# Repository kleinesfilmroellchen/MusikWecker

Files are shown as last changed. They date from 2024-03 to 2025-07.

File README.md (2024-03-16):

# MusikWecker

MusikWecker ("music alarm clock") is an ESP8266-based alarm clock that plays music instead of horrible beeps.

Features:
- Music playback from SD card; various common formats like AAC, MP3, FLAC, WAV etc. supported
- Multiple, customizable alarms with various music playback modes
- Time synchronization via NTP
- Accurate local time and time zone support
- Many aesthetically appealing clock faces
- Low power consumption thanks to ESP8266 light sleep

## Development

Use a recent Arduino IDE or CLI, and make sure all libraries are up-to-date. (Library definition in a sketch config will follow shortly.)

Generate the auto-generated files by running `python .`. (Python >= 3.9, see requirements.txt) This is necessary when you change the generator scripts or when modifying or adding graphics. The compiler will only complain about missing headers the first time you forget this.

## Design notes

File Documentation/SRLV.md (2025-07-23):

# Single-bit Run Length Video (SRLV)

| | |
| --- | --- |
| Version | 0.3 |

Single-bit Run Length Video, abbreviated with SRLV, is a simple video format for black-and-white (1 bit per pixel) intended for software decoding on weak hardware. With the mildly optimized SRLV optimization in this repository, an ESP8266 (a single Xtensa core at 160MHz) can decode 833 frames per second (1.2ms per frame) from 80MHz flash. The small amount of time spent on decoding video allows a microcontroller core to perform all the other time-consuming duties of video playback (audio decoding, I2S communication with the audio DAC, SPI communication when reading audio and/or video from an SD card, I2C or SPI communication with the display) without much worry that the video decoding part will slow it down.

The `compression` directory contains the Python SRLV encoder. It's currently not very configurable apart from the input file, and there's some commented-out code that was used in developing the codec. If you are interested, you can play with these to come up with an even better scheme. Please leave a PR in this case and I may update SRLV (which may include a rename, since the name describes the compression scheme precisely).

> [!NOTE]
> Notes like this one are purely informational and do not specify the format beyond the specification text.

- auto-gen TOC;
  {:toc}

## Video Format

SRLV only performs intra-frame compression, and allows reusing identical frames (such as relatively common pure white or black frames). At present, only the single-frame format of SRLV is specified, and it is not containerized, so external knowledge of the video's dimensions are required to decode it correctly. A simple container format will be specified at a later point and added to this document.

## Frame format

This section specifies a single SRLV frame's raw format. Such frames may be stored using the `srlvf` (SRLV Frame) extension, and `image/srlvf` MIME type. Note that since this is a raw uncontainerized frame, there is no information about the frame's dimensions.

Encoding a frame is done with the following steps:

- The frame is converted to 1BPP XBM-compatible bit layout, including padding.
- The frame is optionally encoded as an inter-frame delta, i.e. a difference from the previous frame.
- Alternatively, the frame's scanlines are optionally converted to a back-and-forth (snake) format.
- The binary data is compressed using one of two methods:
  - Alternating run-length encoding followed by packing with nibble/byte entropy coding.
  - Pixel delta coding followed by black-run/raw coding.

There are six ways of encoding a frame. The numeric value of each method is prefixed as a byte in front of the encoded data, and the name given here will be used throughout the specification.

| Method | Name | Encoding ID |
| --- | --- | --- |
| RLE with nibble/byte entropy coding | Nibble | 0 |
| RLE with nibble/byte entropy coding and inter-frame delta | Nibble Delta  | 1 |
| RLE with nibble/byte entropy coding and snaking scanline reshuffling | Nibble Snake  | 2 |
| Pixel delta with black-run/raw coding | Pokémon | 3 |
| Pixel delta with black-run/raw coding and inter-frame delta | Pokémon Delta | 4 |
| Pixel delta with black-run/raw coding and snaking scanline reshuffling | Pokémon Snake | 5 |

Decoding simply performs the encoding steps in reverse order, using the encoding method specifier to decide which decoding steps (including the two optional preprocessing steps) to perform. Many embedded applications can already use images in XBM format, so the first step doesn't usually have to be applied in reverse in the decoder.

### Conversion to XBM

Frames contain one bit per pixel. The conventional interpretation is 1 = white, 0 = black, but depending on the context any two-color mapping is possible. It is recommended that 1 be assigned the brighter color.

Individual pixel's bits are packed into bytes according to XBM format. This means that pixels are first arranged into a left-to-right, top-to-bottom bitstream. Within the bitstream, consecutive scanlines are therefore arranged top-to-bottom, and the pixels in a scanline appear left-to-right.

> [!NOTE]
> This bit order is equivalent, among many others, to the Quite OK Image Format's (QOI) pixel order, the draw order for CRT televisions, as well as most video signals.

The bitstream is split into bytes, with zero padding at the end. Each byte contains the bits in LSB to MSB order, matching the X Bitmap (XBM) encoding format.

> [!NOTE]
> Run-length encoding does not care about the byte layout, just the bitstream with zero padding. The byte format is specified so that the output of the decompressor, which necessarily needs to have a byte-level format, is properly defined.

### Inter-frame delta coding

This preprocessing step encodes the bitstream as a delta from the previous frame. The unencoded bitstream $y_0$ of the previous frame is bit-wise XORed with the unencoded bitstream $y_1$ of the current frame, such that each bit of the output $x_1$ is given as $x_1[i] = y_0[i] + y_1[i]$.

> [!NOTE]
> For implementation, a byte-wise XOR on the XBM-formatted data of each frame has the same effect as the bitwise XOR.

Inter-frame delta coding methods cannot be used on the first frame.

### Scanline snake reshuffling

This preprocessing step reorders bits in the image before compression / after decompression. The final result is a bit order that "snakes" back and forth across the image. This processing step cannot be combined with inter-frame delta coding.

> [!NOTE]
> Combining snake and delta coding rarely yields better compression under either of the two schemes, so it was removed to speed up close-to-optimal encoding and simplify decoding.

When performing snake reshuffling, every second scanline (horizontal row of pixels) of the image is reversed. The first scanline is not reversed. Reversing means full bit reversal, not just byte reversal. This has the effect that the bits do not scan the image scanline-wise left-to-right, but alternatingly left-to-right and then right-to-left. 

It is recommended to use byte-aligned image widths (pixel count divisible by 8) to accelerate implementations. Some implementations can only handle encoding modes 2 and 5 when this is the case.

### "Nibble" compression

The frame bitstream is run-length encoded using alternating runs of black and white pixels. The first run is black, while the second is white, the third is black again and so on. A run may have any length of 0 to 127 (both inclusive). Runs of length 0 are explicitly valid.

> [!NOTE]
> Run length 0 is used to split long runs up without complicating the format with variable-length codes. For instance, a run of 300 black can be encoded as a 127-bit run of black, a 0-bit run of white (meaning no white pixels at all), another pair of those, and finally a 46-bit run of black:
>
> `0x7f 0x00 0x7f 0x00 0x2e`
>
> For arbitrary data, run length 0 is absolutely necessary.

The final run may be shorter than the remaining number of bits. In this case, the run extends to the end of the bitstream.

> [!NOTE]
> This rule allows saving on many split runs like above for large single-color surfaces, especially when they cover most or all of the image. For example, solid black may be encoded with empty data and solid white with `0x00` regardless of the image size. This is one of the reasons that the image size (and therefore bitstream size) needs to be known.

RLE yields a list of numbers, each from 0 to 127 inclusive. Byte/nibble entropy coding packs these numbers into bytes, using one of two byte formats:

- Byte encoding: A single number is encoded in a byte.
- Nibble encoding: Two numbers are encoded in a byte, using the two nibbles. The top nibble is occupied by the first number in the RLE stream, and the bottom nibble is occupied by the second number.

The topmost bit (MSB) of a byte identifies the kind of coding used. `1` means byte encoding, while `0` means nibble encoding.

For byte encoding, the whole range of values is supported. For nibble encoding, the top nibble may occupy values 0-7 inclusive (using three bits), and the bottom nibble may occupy values 0-15 inclusive (using four bits).

> [!NOTE]
> There are many ways of packing the same numbers into this entropy coding scheme. The reference implementation probably does not implement the best one, and in fact for a while it had a significant inefficiency, restricting the bottom nibble to the same 0-7 range.

### "Pokémon" compression

The frame bitstream is first pixel-delta encoded, and then black portions are run-length encoded.

> [!NOTE]
> The name "Pokémon" was chosen for the pixel delta-based format since it was loosely inspired by part of the compression method used for encoding Pokémon battle sprites in Pokémon Red and Blue (1996/1998). This compression method, addressing many of the same issues as this one (highly limited memory and relatively limited processing power), is surprisingly sophisticated and very interesting in its own right (and the cause of the infamous glitch Pokémon MissingNo's appearance), details can be found [here](https://www.youtube.com/watch?v=aF1Yw_wu2cM).
>
> Pokémon usually performs better on images with large amounts of noise, as its overhead for fast-changing pixels is significantly less than with the simple RLE scheme.

To perform pixel-delta encoding, each pixel is encoded as the XOR of itself with the previous pixel in bitstream order. The previous pixel of the first pixel is black.

For the run-length coding of these deltas, each byte may encode either:

- a run of up to 128 pixels of black (0) or
- 7 uncompressed pixels, in LSB-to-MSB-order

The topmost bit (MSB) of a byte identifies the kind of coding used. `1` means black RLE, while `0` means raw encoding. For the RLE, a bias of 1 is used, so a codeword of `0x80` represents not a run of length 0, but length 1.

> [!NOTE]
> Unlike in the simple RLE, since arbitrary codewords can follow one another, it is not necessary to have runs of length 0.

If the data does not specify all pixel values, the rest of the pixels are filled with 0.

### Turtle compression

Data for a frame consists of a frame header (9 byte) followed by any number of objects drawn onto the image.

The frame header starts with an info byte of the form `i0000000`:

- `i` is a flag determining whether to invert the frame colors at the end. By default, white (1) pixels are drawn on top of a black (0) background. If inverted, frames effectively have black pixels drawn on top of a white background.

Following this are 8 bytes for the Huffman coding table. Each byte contains a 3-bit entry bitsize (biased by 1, so 1-8) and an entry. The bitsize occupies the topmost 3 bits while the entry itself is situated at the least significant bits and cut off according to the given bitsize. (Any bitsize above 5 is illegal, as the entry only has 5 bits available.)

The entries for the table are always in this order:

- 135L
- 90L
- 45L
- F1
- FN
- FX
- 45R
- 90R
- 135R

See below for command names. In the following only these command names are used, which are substituted with their respective Huffman code in each frame.

#### Objects

An object starts with two header bytes of the form `0xxxxxxx 0yyyyyyy`:

- `x` is the X offset of the first pixel.
- `y` is the Y offset of the first pixel.

For solid objects, turtle graphics logic is used. The turtle has a current position on the image, as well as a grid direction that is aligned to 45 degrees (i.e. diagonal or horizontal or vertical). The initial facing direction is always down right (positive X and Y). Any command instructs the turtle to optionally change its facing direction, and then take at least one step in that new direction. The commands are:

- `90L`: Rotate 90 degrees left, then take one step.
- `90R`: Rotate 90 degrees right, then take one step.
- `45L`: Rotate 45 degrees left, then take one step.
- `45L`: Rotate 45 degrees right, then take one step.
- `135L`: Rotate 135 degrees left, then take one step.
- `135R`: Rotate 135 degrees right, then take one step.
- `F1`: Move forward one step without rotating.
- `FN`: Move forward at least 2 steps without rotating.
- `FX`: Move forward until starting position or image border is reached.

The `FN` command is the only one with a single parameter, namely the number of steps to move forward. The steps are encoded using Rice-Golomb coding with order `k = 2` and bias 1, such that the step count 2 is encoded as value 1.

The turtle commands automatically end once the starting location is reached again. The starting position is always filled in, but there’s no initial step taken in the starting direction. Any surface enclosed by the edge drawn by the turtle is filled in. The usual even-odd filling algorithm is used: Any pixel is filled in if any line from it to infinity crosses through an odd number of edges. The filling algorithm disregards any existing objects in the image.

The object is combined onto the full image by means of an XOR operation for each pixel, i.e. every pixel filled by the object is inverted in the final image.

#### Single-pixel trailer

Single-pixel trailer objects are a list of pixels to be set.

After the same common header as the normal objects use, each following coordinate is encoded using Rice-Golomb coding with order `k = 5` and zig-zag coding, such that 1 -> 1, -1 -> 2, 2 -> 3, -2 -> 4, 3 -> 5 etc.

All pixel coordinates, each a pair (x, y), are encoded as the difference from the previous one.

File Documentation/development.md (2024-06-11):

# Developer Guide

Use the Arduino IDE or CLI. There's VSCode integration too!

clangd or the Microsoft C/C++ language server should work well.

Formatting with clang-format is necessary for contributions. The config is in the standard .clang-format, MusikWecker uses minimally modified WebKit style.

## Debugging and logging

Since the serial port's pins are in use for other purposes, debugging via serial is not possible. (There is an option in Definitions.h to enable serial setup and prints, but it does not work if SD card and I2S code is not disabled.) Instead, debugging via TCP has been implemented. The MusikWecker provides a TCP server on port 1000, and connecting to that TCP server allows you to receive log messages.

The TCP logging does not easily handle early boot messages, or early boot failures. Debugging those is exceptionally hard to impossible on the MusikWecker and comes down to trial and error, i.e. commenting and un-commenting code until an offending statement is found and using guesswork to determine the underlying issue. Sometimes, serial debugging is possible here; you may need to disable the SD card initialization and/or audio management initialization.

## If the Bad Apple demo is slow

(i.e. stuttery video playback, but fine audio playback)

Force all important I2S routines into IRAM, like so:

```cpp
// I2S.h in ESP8266 core libraries
// insert the IRAM_ATTR in the appropriate places:

  // from Stream
  virtual int IRAM_ATTR available();
  virtual int IRAM_ATTR read(); // Blocking, will wait for incoming data
  virtual int IRAM_ATTR peek(); // Blocking, will wait for incoming data   
  virtual void IRAM_ATTR flush();

  // from Print (see notes on write() methods below)
  virtual size_t IRAM_ATTR write(uint8_t);
  virtual size_t IRAM_ATTR write(const uint8_t *buffer, size_t size);
  virtual int IRAM_ATTR availableForWrite();

```

[An issue to enable this via a configurable option has been opened upstream](https://github.com/esp8266/Arduino/issues/9115).

## TODOs because I forget

Some of the things I still need to implement. In rough order of priority

### Must

- Bugs/QOL
	- File list doesn't reload everywhere when files are moved and deleted
	- Diagnostics page is broken
- The entire alarm system
	- Creating and deleting alarms
	- Alarm settings (which are available?)
	- Executing alarms
	- Correct wakeup before an alarm runs (at least 10s to allow WiFi reconnect)
- Software volume control
- Power saving shenanigans
	- Flash clock-down for the same reasons.
- Play music when selected in file view
- Important settings
	- Configure NTP update interval
		- 60s
		- 5min
		- 30min
		- 24h
	- Configure NTP server

### Want

- Nicer interface for yes/no selection menus
- Web UI for configuring more complex stuff
	- Name alarms
	- Specifying 
	- Rename files
- Talk to Home Assistant for updating alarm times (since HA has an easier time receiving alarm data from Google services and the like)
- MP3 player
	- "Currently playing" page (in the clock menu?)
	- Play entire folder
	- Index all music, allow playback by artist, album, etc.

### Nice to have

- Put together a BOM for making a single PCB for this
- Design a single PCB for this
- Manufacture a single PCB for this
- World domination

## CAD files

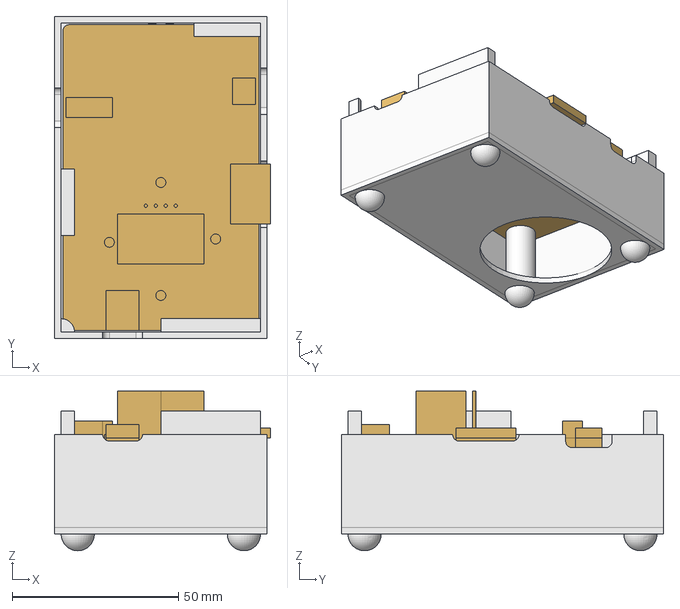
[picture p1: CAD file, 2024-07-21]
EDA/MusikWeckerCase.FCStd
65.0 x 97.0 x 48.0 mm
PCBModel
TopWithConnectors

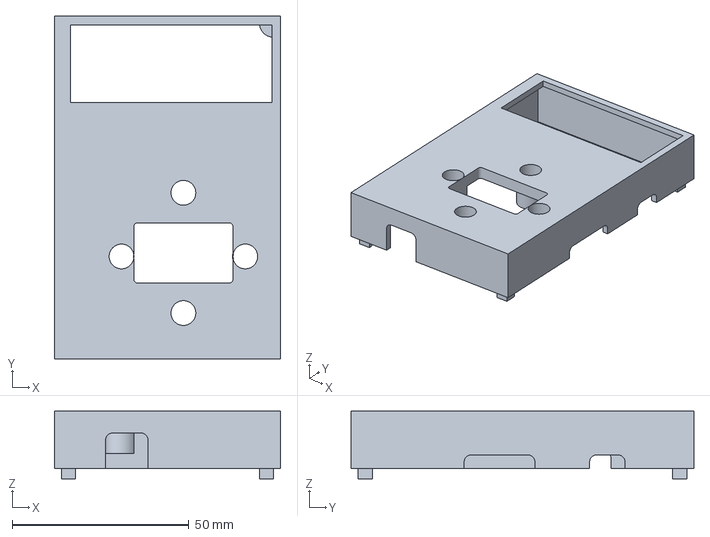
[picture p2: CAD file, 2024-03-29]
EDA/MusikWeckerCase_top.3mf
64.0 x 97.0 x 19.2 mm

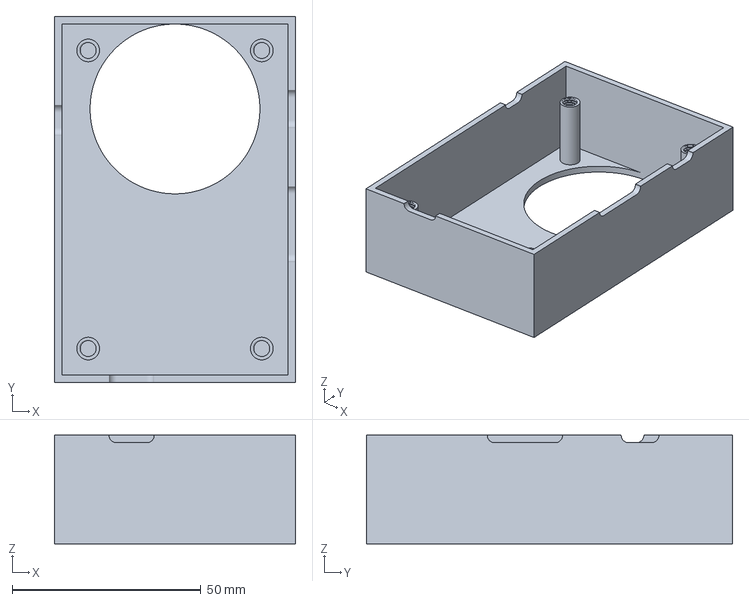
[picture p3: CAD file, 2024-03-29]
EDA/MusikWeckerCase_bottom.3mf
64.0 x 97.0 x 28.8 mm

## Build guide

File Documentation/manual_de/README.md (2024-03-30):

# Benutzerhandbuch für den MusikWecker

Dieses Benutzerhandbuch ist für Benutzer\*innen des MusikWeckers gedacht, nicht für Entwickler.

Diese Seite behandelt die Grundlagen des Weckers. Auf weiteren Seiten (Liste links) finden sich detaillierte Informationen zu anderen Aspekten.

- auto-gen TOC;
  {:toc}

## Bediengrundlagen

Der MusikWecker besitzt vier Knöpfe zur Bedienung, die jeweils eine übliche Funktion besitzen:

- _Rechts_: OK/Enter
- _Oben_: Zum darüberliegenden Menüpunkt navigieren
- _Unten_: Zum darunterliegenden Menüpunkt navigieren
- _Links_: Abbrechen, Menü verlassen

Wird ein Knopf längere Zeit gedrückt, so wird der Knopf wiederholt aktiviert.

In den meisten Menüs können Optionen dementsprechend durch Scrollen nach oben und unten ausgewählt werden. Eine Option wird durch _Rechts_ bestätigt, und _Links_ dient zum Abbrechen oder Verlassen des Menüs.

Wenn der Wecker in den Ruhezustand geht, kann nur _Links_ ihn aufwecken.

## Hauptmenü

Vom Startbildschirm aus (dem Uhrbildschirm) kann das Hauptmenü mittels _Rechts_ aufgerufen werden. Das Hauptmenü besteht aus den folgenden Elementen:

- Uhrdesign: Auswahl der Uhr, die angezeigt wird.
- Wecker: Konfiguration von Weckern.
- Dateiverwaltung: Verwaltung der Dateien auf der SD-Karte.
- Einstellungen: Verschiedene Einstellungen des MusikWeckers
- Diagnostik: Diagnosemenüs, die den detaillierten Zustand des Weckers zeigen.

## Einstellungen

Die folgenden Einstellungen sind verfügbar. Sie werden dauerhaft gespeichert und werden nach einem Neustart des Weckers wiederhergestellt.

- Auto-Abschaltung: Zeitdauer, nach der der Wecker in den Ruhezustand geht.
- Zeitzone: Zeitzone der Uhr. Die Zeitzonen sind von Osten nach Westen geordnet.
- Debugging: Firmware-Debugging. Dies aktiviert die Anzeige von Debugging-Nachrichten (in der Regel nur sichtbar, falls der Wecker kurz danach abstürzt), sowie verschiedene Debugging-Funktionen wie die Anzeige von Uhren-Zeichnungszeiten auf dem Startbildschirm.

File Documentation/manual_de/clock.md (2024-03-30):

# Uhr

Der Uhrbildschirm ist der Startbildschirm des Weckers. Er zeigt die aktuelle Uhrzeit entsprechend dem aktuellen Uhrdesign, das aktuelle Datum (falls aktiviert), sowie rechts oben mehrere Icons, die den Zustand des Weckers beschreiben:

- Funksymbol: Wecker ist mit einem WLAN-Netzwerk verbunden.
- Kreuz anstelle des Funksymbols: Wecker ist nicht mit einem Netzwerk verbunden.
- Uhr mit Funkwellen: Wecker hat soeben seine Uhrzeit synchronisiert. Dies geschieht für gewöhnlich jede Minute, und das Symbol wird einige Sekunden angezeigt.
- Wecker: Mindestens ein Wecker ist aktiv.
- Lautsprecher: Ton wird wiedergegeben.

## Uhrdesign

Das Uhrdesign-Menü (erreichbar im Hauptmenü) erlaubt die Auswahl des Uhrdesigns des Weckers. Wird die Auswahl in diesem Menü mehr als fünf Sekunden nicht bewegt, zeigt die rechte Seite des Bildschirms eine Vorschau des aktuell angewählten Designs. Durch _Rechts_ kann dieses Design ausgewählt werden.

Die folgenden Designs sind aktuell verfügbar:

- Digital: Einfache, große Digitaluhr ohne Sekundenanzeige.
- Digital (Sekunden): Identisch zur normalen Digitaluhr, allerdings mit Sekundenanzeige.
- Analog (minimalistisch): Analoguhr mit Stundenstrichen ohne Beschriftungen.
- Rotierende Segmente: Drei rotierende Segmente, die (von innen nach außen) Stunden, Minuten und Sekunden anzeigen. Die Größe des Segments entspricht dem Abstand eines analogen Zeigers von der Zwölf-Uhr-Position.
- Binär: Binäruhr, die von unten nach oben Stunden, Minuten und Sekunden als Binärzahl anzeigt.
- Binär (Tagsekunden): Binäruhr, die die Sekunden des Tages anzeigt.

## Uhrzeit und Zeitsynchronisation

Der Wecker ruft die aktuelle Uhrzeit über das Internet mithilfe des Network Time Protocols (NTP) ab. Da der Wecker die Uhrzeit nicht persistent speichert, ist er auf die Netzwerkzeitsynchronisation angewiesen, und zeigt beispielsweise nach dem Hochfahren bis zur ersten Netzwerkverbindung keine sinnvolle Uhrzeit an.

Zur Synchronisation muss auf einen NTP-Server zugegriffen werden, der im Idealfall jederzeit verfügbar sein sollte, damit eine Resynchronisierung zu beliebigen Zeitpunkten möglich ist. Aktuell wird immer der `europe.pool.ntp.org`-Server ausgewählt, der einen zufälligen europäischen NTP-Poolserver abruft. Der NTP-Pool ist allgemein zu empfehlen, da er auf viele tausende Server zurückgreifen kann und damit kaum störungsanfällig ist. In einer zukünftigen Firmwareversion werden diese NTP-Server als Auswahl zur Verfügung stehen:

- `pool.ntp.org`, `0.pool.ntp.org`, `1.pool.ntp.org`, `2.pool.ntp.org`, `3.pool.ntp.org`: Die globalen NTP-Poolserver. Die Server mit vorangestellter Ziffer sollten nur verwendet werden, falls die anderen nicht erreichbar sind.
- `africa.pool.ntp.org`, `asia.pool.ntp.org`, `europe.pool.ntp.org`, `north-america.pool.ntp.org`, `oceania.pool.ntp.org`, `south-america.pool.ntp.org`: Kontinentspezifische NTP-Pools, die entgegen dem globalen Pool bevorzugt werden sollten, da sie geographisch nähere Server und geringere Antwortzeiten verursachen.
- `de.pool.ntp.org`, `at.pool.ntp.org`, `ch.pool.ntp.org`: Länderspezifische NTP-Pools für DACH, die noch mehr einen Antwortzeit-Vorteil als die Kontinentalpools bieten.
- `time.nist.gov`: Zeitserverpool des staatlichen USA-Metrologieinstituts NIST. Empfehlenswert nur für Verwendung innerhalb der USA.
- `ptbtime1.ptb.de`, `ptbtime2.ptb.de`, `ptbtime3.ptb.de`, `ptbtime4.ptb.de`: Zeitserver der Physikalisch-Technischen Bundesanstalt. Empfehlenswert nur für Verwendung innerhalb Deutschlands.
- Gateway: Verwendet den aktuellen Netzwerk-Gateway als NTP-Server. In vielen einfachen Heimnetzwerken fungiert der Router bzw. Gateway auch als NTP-Server (dies kann beispielsweise bei den FRITZ!Box-Routern von AVM problemlos über das Webinterface eingerichtet werden). Bei seltenem Netzwerkwechsel ist der Vorteil hiervon eine sehr geringe Antwortzeit und Netzwerklast, sowie eine einfache und flexiblere Umkonfiguration der NTP-Server, die jetzt nur noch im Router vorgenommen werden müssen.

Unabhängig von der Zeitsynchronisation kann in den Einstellungen eine Zeitzone gewählt werden. Die Zeitzonendatenbank, welche beispielsweise Informationen über Sommerzeitumstellungen enthält, wird vom Wecker nicht automatisch aktualisiert und muss durch ein Firmware-Update erneuert werden. Dank der recht seltenen Änderungen in Zeitzonenkonfigurationen ist dies nur notwendig, wenn der Wecker erkennbar von der eigentlichen Uhrzeit in einer Zeitzone abweicht.

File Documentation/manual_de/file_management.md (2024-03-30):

# Dateiverwaltung

Der Wecker benutzt eine Micro-SD-Karte, um dort gespeicherte Musik zum Wecken zu verwenden. Er stellt außerdem grundlegende Dateiverwaltung zur Verfügung, allerdings muss die zu verwendende Musik vorher mit einem anderen Gerät auf der SD-Karte abgelegt werden.

- auto-gen TOC;
  {:toc}

## Kartenformat

Der Wecker unterstützt nur Karten, die ein FAT-Dateisystem (FAT16, FAT32, exFAT) haben und entsprechend dem SD-Standard formatiert sind. Die Formatierung nach diesen Kriterien wird z.B. vom offiziellen SD-Karten-Formatierungstool der SD Association durchgeführt, welches [hier](https://www.sdcard.org/downloads/formatter/) kostenlos heruntergeladen werden kann.

Zum Einlegen oder Entnehmen einer SD-Karte sollte der Wecker nicht eingeschaltet sein, da dies die Daten auf der SD-Karte beschädigen kann. Außerdem kann der Wecker mit dem Entnehmen oder Einlegen der SD-Karte zur Laufzeit nicht gut umgehen und stürzt eventuell ab.

## Dateiansicht

Verschiedene Menüs des Weckers bieten eine Dateiansicht, die die Dateien eines Verzeichnisses auflistet. Das sind z.B. das Lösch- und Verschiebemenü sowie die Menüs zur Auswahl einer Musikdatei für einen Wecker. Die Menüs besitzen immer denselben Aufbau: In einer Liste, wie auch in anderen Listenmenüs, werden die Dateien des aktuellen Ordners angezeigt, zwischen denen mit _Oben_ und _Unten_ navigiert werden kann. Die ersten beiden Einträge dieser Liste sind besonders.

Der erste Eintrag hat als Namen den vollständigen Pfad des aktuellen Verzeichnisses. Je nach Art des Menüs kann dieser Eintrag so wie andere Dateien ebenfalls angewählt werden, um das Verzeichnis (anstatt einer einzelnen Datei) anzuwählen. Beispielsweise kann ein Verzeichnis im Löschmenü angewählt werden, um das gesamte Verzeichnis zu löschen. Besteht keine Anwahlmöglichkeit für ein Verzeichnis (d.h. es können nur Dateien oder überhaupt nichts angewählt werden), so kann _Rechts_ dennoch betätigt werden, um die Verzeichnisansicht zu aktualisieren. (In der Regel sorgt dies nicht für eine sichtbare Änderung der Anzeige.)

Der zweite Eintrag hat als Namen "..". Dieser Eintrag beschreibt, so wie auch in Klammern angegeben ist, das Elternverzeichnis des aktuellen Verzeichnisses, also das nächste übergeordnete Verzeichnis. Die Anwahl dieses Eintrags öffnet das übergeordnete Verzeichnis in der Dateiansicht. (Dieser Eintrag hat keine Auswirkungen, sollte bereits das Basisverzeichnis der SD-Karte geöffnet sein.) Dazu ist wichtig zu bemerken, dass _Links_ absichtlich **nicht** das Elternverzeichnis öffnet, sondern das Dateimenü schließt und zum vorherigen Menü zurückkehrt. Dies erleichtert das Verlassen der Dateiansicht, wenn gerade ein tief verschachteltes Dateimenü geöffnet ist. Da der ".."-Eintrag der zweite Eintrag der Liste ist, ist es recht einfach, schnell einige Verzeichnisse nach oben zu navigieren.

Das Anwählen von Unterverzeichnissen, die als normale Einträge geführt werden, öffnet dieses Unterverzeichnis in der Dateiansicht. Soll dieses Verzeichnis selbst angewählt werden, kann in der jetzt sichtbaren Liste entsprechend der erste Eintrag gewählt werden.

Die Sortierung der gewöhnlichen Einträge hat aktuell technische Hintergründe und entspricht vermutlich dem Erstellzeitpunkt der Dateien bzw. Verzeichnisse.

## Dateiverwaltungsmenü

Das Menü "Dateiverwaltung", welches sich im Hauptmenü findet, ermöglicht generelle Verwaltung der Dateien auf der SD-Karte. Die folgenden Aktionen sind möglich:
- Dateiansicht: Ansicht der Dateien auf der SD-Karte. Aktuell bietet dies lediglich die Möglichkeit, durch die Verzeichnisse zu navigieren und die Dateien der verschiedenen Verzeichnisse anzuzeigen. Die Anwahl von Dateien oder Verzeichnissen hat keine Funktion.
- Verschieben: Verschieben von Dateien in andere Verzeichnisse. Nach der Anwahl einer Datei kann ein anderes Verzeichnis ausgewählt werden. Nach der Bestätigung der Verschiebeaktion wird die Datei ans Ziel verschoben.
- Löschen: Löschen von Verzeichnissen oder Dateien. Nach der Anwahl einer Datei oder eines Verzeichnisses und der Bestätigung wird das entsprechende Element dauerhaft gelöscht. Der Wecker verfügt nicht über einen Papierkorb!

Der Wecker verfügt bewusst nicht über eine Umbenennungsfunktion, da Texteingabe mit vier Knöpfen unmöglich gut funktionieren kann. Für komplexere Dateiverwaltungsaufgaben sollte die SD-Karte mit einem Computer verbunden werden.

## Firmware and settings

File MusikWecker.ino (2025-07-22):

/**
		 Music alarm clock - ESP8266

		 by kleinesfilmröllchen

		 --------- Hardware:

		 SD card reader on hardware SPI

		 OLED screen SSD1306-based I²C on SCL/SDA

		 Buttons for menuing
		 - Up and Down on analog 0 (voltage divider hack; Up at 3.3V, Down at 0V, Neutral at 1.6V)
		 - Left  on pin D3 with internal pull-up
		 - Right on pin D0 with external pull-up

		 The buttons are not software-debounced, so it is recommended to hardware-debounce them.
		 This can simply be done with a 0.1µF (or similar) capacitor in parallel to the button.
*/

// Needs to be included first in order to set up certain defines for libraries.
#include "Definitions.h"

#include "Audio.h"
#include "ClockFaces.h"
#include "Debug.h"
#include "DisplayUtils.h"
#include "Menu.h"
#include "Settings.h"
#include "TimeManager.h"
#include "string_constants.h"
#include "zonelist.h"
#include <AceTime.h>
#include <ArduinoOTA.h>
#include <EEPROM.h>
#include <ESP8266WiFi.h>
#include <ESP8266mDNS.h>
#include <U8g2lib.h>
#include <gpio.h>
#include <spiram-fast.h>
#include <umm_malloc/umm_heap_select.h>
#include <user_interface.h>

void setup();
void loop();

//// global constants

// display
Display display(U8G2_R0);
// SD card
SdFs card;

EepromSettings eeprom_settings;

//// global vars

// state of the buttons in the previous loop
uint8_t last_buttons = 0xff;
// ms time when the buttons last changed; use this to register repeated button presses on button hold
uint32_t button_change_time = 0;
// ms delta since the last time a button press was executed when holding a button
int32_t button_hold_time_delta = 0;
// ms time when the last loop execution happened
uint32_t previous_loop_time = 0;
// ms time since the last draw call was issued
uint32_t drawTime = 0;

// currently open menu, e.g. clock or settings
Menu* current_menu = nullptr;
// current function responsible for clock face drawing
ClockFaces::ClockFace current_clock_face;

void setup()
{
#if USE_SERIAL
	Serial.begin(115200, SerialConfig::SERIAL_8N1, SerialMode::SERIAL_TX_ONLY);
	while (!Serial)
		yield();
	Serial.println();
#endif

	// connect display first for debugging
	if (!display.begin()) {
		// Force initialize serial port to allow for better debugging; we're resetting in a moment anyways
		Serial.begin(115200, SerialConfig::SERIAL_8N1, SerialMode::SERIAL_TX_ONLY);
		while (!Serial)
			yield();
		Serial.println(F("SSD1306 connection FAILED."));
		ESP.reset();
	} else {
		display.setCursor(LINE_HEIGHT, 0);
		display.setBusClock(DISPLAY_CLOCK_SPEED);
		debug_print(F("Display ok."));
	}
	yield();

	// ----------------------------------------------------------
	// init
	// wifi
	WiFi.mode(WIFI_STA);
	WiFi.begin(STASSID, STAPSK);
	WiFi.setAutoReconnect(true);
	yield();

	{
		HeapSelectIram iram;
		ArduinoOTA.setHostname(HOSTNAME);
		ArduinoOTA.begin();
		MDNS.begin(HOSTNAME);
	}

	// pins
	pinMode(PIN_BUTTON_LEFT, INPUT_PULLUP);
	pinMode(PIN_BUTTON_RIGHT, INPUT_PULLUP);

	// eeprom
	EEPROM.begin(SETTINGS_SIZE);
	EEPROM.get(SETTINGS_ADDRESS, eeprom_settings);
	// The timezone index should only reach values of ~ 300-400 in extreme future situations.
	// Therefore, the uninitialized state of the fake EEPROM which has all bits set can be used
	// to detect uninitialized or erased EEPROM.
	if (eeprom_settings.timezone == 0xFFFF) {
		debug_print(F("EEPROM uninitialized, replacing by default settings."));
		eeprom_settings = {};
		save_settings();
	}

	// connect SD card
	// "Note that even if you don’t use the hardware SS pin, it must be left as an output or the SD library won’t work."
	pinMode(SS, OUTPUT);
	bool sdConnectResult = card.begin(SD_CONFIG);
	if (!sdConnectResult) {
		debug_print(F("Connection to SD card FAILED. Error code:"));
		debug_print(card.sdErrorCode());
		debug_print(F("Data:"));
		debug_print(card.sdErrorData());
		// ESP.reset();
	} else {
		debug_print(F("SD ok."));
	}
	yield();

	debug_print(F("Trying to setup audio..."));
	audioLogger = &DebugManager::the();
	AudioManager::the();

	display.firstPage();
	do {
		display.setFont(MAIN_FONT);
		// text should not override display data behind characters, this enables "transparency"
		display.setFontMode(1);
	} while (display.nextPage());

	TimeManager::the().update_if_needed();

	current_menu = create_menu_structure();

	// initialize timing variables
	button_change_time = previous_loop_time = drawTime = millis();
}

void loop()
{
	// the timing millisecond counter that rolls around every minute or so
	auto current_loop_time = millis();
	yield();

	ArduinoOTA.handle();
	yield();
	MDNS.update();
	yield();
	TimeManager::the().update_if_needed();
	yield();
	DebugManager::the().handle();
	yield();

	// read buttons, some bit magic here
	uint8_t buttons = 0x0f & (((analogRead(PIN_BUTTON_UPDOWN) > 750) << BUTTON_UP_BIT) | ((analogRead(PIN_BUTTON_UPDOWN) < 350) << BUTTON_DOWN_BIT) | ((~digitalRead(PIN_BUTTON_RIGHT) & 1) << BUTTON_RIGHT_BIT) | ((~digitalRead(PIN_BUTTON_LEFT) & 1) << BUTTON_LEFT_BIT));

	// if a button is held and the time since button change exceeds the hold time "delay"...
	if ((current_loop_time - button_change_time > BUTTON_HOLD_DELAY) && (buttons != 0)) {
		// decrease delta to next simulated button press by loop delta
		button_hold_time_delta -= current_loop_time - previous_loop_time;
	} else {
		// else reset delta
		button_hold_time_delta = BUTTON_HOLD_REPEAT_DELAY;
	}

	// temporary storage for a possibly different new menu
	Menu* newMenu = current_menu;
	// handle buttons
	if (buttons != last_buttons || (button_hold_time_delta < 0)) {
		yield();
		newMenu = newMenu->handle_button(buttons);
	}

	// any button state is different: update last button time
	if (buttons != last_buttons) {
		button_change_time = current_loop_time;
		button_hold_time_delta = BUTTON_HOLD_REPEAT_DELAY;
	}
	// reset time to next simulated button press if a button press was just simulated
	if (button_hold_time_delta < 0) {
		button_hold_time_delta += BUTTON_HOLD_REPEAT_DELAY;
	}

	yield();

	// draw if menu changed due to buttons
	if (current_menu != newMenu) {
		newMenu = newMenu->draw_menu(&display, current_loop_time - drawTime);
	}
	// draw if menu wants to refresh
	else if (newMenu->should_refresh(current_loop_time - previous_loop_time)) {
		yield();
		current_menu = newMenu->draw_menu(&display, current_loop_time - drawTime);
		drawTime = current_loop_time;
	}

	// store new menu
	current_menu = newMenu;

	// TODO: light sleep regularly crashes the ESP8266, and I don't quite know why.
	// The entire light sleep setup itself is rather finnicky in the first place, and there's zero good documentation on it.
	// Since the clock can restore its state with ease after a power cycle (usually needing <10s to reconnect to Wifi and fetching NTP),
	// this is not really an issue, but it annoyingly makes the screen turn on sporadically.
	if (current_loop_time - button_change_time > eeprom_settings.sleep_time && !AudioManager::the().is_playing()) {
		debug_print(F("Running light sleep..."));
		display.setPowerSave(true);

		delay(10);
		wifi_set_opmode(NULL_MODE);
		wifi_fpm_set_sleep_type(LIGHT_SLEEP_T);
		wifi_fpm_open();
		// allow both of these to interrupt sleep
		gpio_pin_wakeup_enable(GPIO_ID_PIN(PIN_BUTTON_LEFT), GPIO_PIN_INTR_LOLEVEL);
		// doesn't seem to work...
		gpio_pin_wakeup_enable(GPIO_ID_PIN(PIN_BUTTON_RIGHT), GPIO_PIN_INTR_LOLEVEL);
		// TODO: Use time until next alarm for the maximum sleep time
		wifi_fpm_do_sleep(0xFFFFFFFF);
		delay(10);

		// disable power save again
		display.setPowerSave(false);
		wifi_fpm_set_sleep_type(NONE_SLEEP_T);
		WiFi.forceSleepWake();
		WiFi.begin();
		TimeManager::the().force_update();
		button_change_time = current_loop_time = millis();
	}
	yield();

	// store state and time
	last_buttons = buttons;
	previous_loop_time = current_loop_time;
}

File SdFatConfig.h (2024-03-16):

// Override default SdFat configuration. (Unfortunately we can't simply redefine all the parameters we need to change...)

/**
 * Copyright (c) 2011-2021 Bill Greiman
 * This file is part of the SdFat library for SD memory cards.
 *
 * MIT License
 *
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
 * THE SOFTWARE IS PROVIDED "AS IS", WITHOUT WARRANTY OF ANY KIND, EXPRESS
 * OR IMPLIED, INCLUDING BUT NOT LIMITED TO THE WARRANTIES OF MERCHANTABILITY,
 * FITNESS FOR A PARTICULAR PURPOSE AND NONINFRINGEMENT. IN NO EVENT SHALL THE
 * AUTHORS OR COPYRIGHT HOLDERS BE LIABLE FOR ANY CLAIM, DAMAGES OR OTHER
 * LIABILITY, WHETHER IN AN ACTION OF CONTRACT, TORT OR OTHERWISE, ARISING
 * FROM, OUT OF OR IN CONNECTION WITH THE SOFTWARE OR THE USE OR OTHER
 * DEALINGS IN THE SOFTWARE.
 */
/**
 * \file
 * \brief configuration definitions
 */
#ifndef SdFatConfig_h
#define SdFatConfig_h
#include <stdint.h>
#ifdef __AVR__
#include <avr/io.h>
#endif // __AVR__
//
#define SDFAT_FILE_TYPE 3
#define USE_UTF8_LONG_NAMES 1
//
// For minimum flash size use these settings:
// #define USE_FAT_FILE_FLAG_CONTIGUOUS 0
// #define ENABLE_DEDICATED_SPI 0
// #define USE_LONG_FILE_NAMES 0
// #define SDFAT_FILE_TYPE 1
//
// Options can be set in a makefile or an IDE like platformIO
// if they are in a #ifndef/#endif block below.
//------------------------------------------------------------------------------
/** For Debug - must be one */
#define ENABLE_ARDUINO_FEATURES 1
/** For Debug - must be one */
#define ENABLE_ARDUINO_SERIAL 1
/** For Debug - must be one */
#define ENABLE_ARDUINO_STRING 1
//------------------------------------------------------------------------------
#if ENABLE_ARDUINO_FEATURES
#include "Arduino.h"
#ifdef PLATFORM_ID
// Only defined if a Particle device.
#include "application.h"
#endif // PLATFORM_ID
#endif // ENABLE_ARDUINO_FEATURES
//------------------------------------------------------------------------------
/**
 * File types for SdFat, File, SdFile, SdBaseFile, fstream,
 * ifstream, and ofstream.
 *
 * Set SDFAT_FILE_TYPE to:
 *
 * 1 for FAT16/FAT32, 2 for exFAT, 3 for FAT16/FAT32 and exFAT.
 */
#ifndef SDFAT_FILE_TYPE
#if defined(__AVR__) && FLASHEND < 0X8000
// 32K AVR boards.
#define SDFAT_FILE_TYPE 1
#else // defined(__AVR__) && FLASHEND < 0X8000
// All other boards.
#define SDFAT_FILE_TYPE 3
#endif // defined(__AVR__) && FLASHEND < 0X8000
#endif // SDFAT_FILE_TYPE
//------------------------------------------------------------------------------
/**
 * Set USE_FAT_FILE_FLAG_CONTIGUOUS nonzero to optimize access to
 * contiguous files.  A small amount of flash is flash is used.
 */
#ifndef USE_FAT_FILE_FLAG_CONTIGUOUS
#define USE_FAT_FILE_FLAG_CONTIGUOUS 1
#endif // USE_FAT_FILE_FLAG_CONTIGUOUS
//------------------------------------------------------------------------------
/**
 * Set ENABLE_DEDICATED_SPI non-zero to enable dedicated use of the SPI bus.
 * Selecting dedicated SPI in SdSpiConfig() will produce better
 * performance by using very large multi-block transfers to and
 * from the SD card.
 *
 * Enabling dedicated SPI will cost extra flash and RAM.
 */
#ifndef ENABLE_DEDICATED_SPI
#if defined(__AVR__) && FLASHEND < 0X8000
// 32K AVR boards.
#define ENABLE_DEDICATED_SPI 1
#else // defined(__AVR__) && FLASHEND < 0X8000
// All other boards.
#define ENABLE_DEDICATED_SPI 1
#endif // defined(__AVR__) && FLASHEND < 0X8000
#endif // ENABLE_DEDICATED_SPI
//------------------------------------------------------------------------------
// Driver options
/**
 * If the symbol SPI_DRIVER_SELECT is:
 *
 * 0 - An optimized custom SPI driver is used if it exists
 *     else the standard library driver is used.
 *
 * 1 - The standard library driver is always used.
 *
 * 2 - An external SPI driver of SoftSpiDriver template class is always used.
 *
 * 3 - An external SPI driver derived from SdSpiBaseClass is always used.
 */
#ifndef SPI_DRIVER_SELECT
#define SPI_DRIVER_SELECT 0
#endif // SPI_DRIVER_SELECT
/**
 * If USE_SPI_ARRAY_TRANSFER is non-zero and the standard SPI library is
 * use, the array transfer function, transfer(buf, size), will be used.
 * This option will allocate up to a 512 byte temporary buffer for send.
 * This may be faster for some boards.  Do not use this with AVR boards.
 */
#ifndef USE_SPI_ARRAY_TRANSFER
#define USE_SPI_ARRAY_TRANSFER 0
#endif // USE_SPI_ARRAY_TRANSFER
/**
 * SD maximum initialization clock rate.
 */
#ifndef SD_MAX_INIT_RATE_KHZ
#define SD_MAX_INIT_RATE_KHZ 400
#endif // SD_MAX_INIT_RATE_KHZ
/**
 * Set USE_BLOCK_DEVICE_INTERFACE nonzero to use a generic block device.
 * This allow use of an external BlockDevice driver that is derived from
 * the BlockDeviceInterface like this:
 *
 * class UsbMscDriver : public BlockDeviceInterface {
 *   ... code for USB mass storage class driver.
 * };
 *
 * UsbMscDriver usbMsc;
 * FsVolume key;
 * ...
 *
 *   // Init USB MSC driver.
 *   if (!usbMsc.begin()) {
 *     ... handle driver init failure.
 *   }
 *   // Init FAT/exFAT volume.
 *   if (!key.begin(&usbMsc)) {
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

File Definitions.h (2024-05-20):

/**
   Definition header.
*/

#pragma once

// enable serial with USE_SERIAL=1
// this WILL break the I2S DAC!
#define USE_SERIAL 0

// F = full framebuffer
// 1 = small partial framebuffer
// 2 = larger partial framebuffer
#define FRAMEBUFFER_SIZE '2'

#include "SdFatConfig.h"
#include "ssid.h"
#include <Arduino.h>
#include <SdFat.h>
#include <U8g2lib.h>
#include <stdint.h>

template <uint64_t numerator, uint64_t denominator, typename Floating = double>
constexpr Floating PI_FACTOR = static_cast<Floating>(numerator) * static_cast<Floating>(PI) / static_cast<Floating>(denominator);

// 30 degrees = π/6 radians
constexpr double PI_DIV6 PROGMEM = PI_FACTOR<1, 6>;
// 90 degrees = π/4 radians
constexpr double QUARTER_PI PROGMEM = PI_FACTOR<1, 4>;
// 135 degrees = 3π/4 radians
constexpr double THREE_QUARTER_PI PROGMEM = PI_FACTOR<3, 4>;

static char const* HOSTNAME PROGMEM = "MusikWecker";

// chip select pin for sd card
constexpr uint8_t PIN_SD_CS = TX;
static const SdSpiConfig SD_CONFIG = {
	PIN_SD_CS,
	DEDICATED_SPI,
	// Board is pretty glitchy above 20MHz even though any SD card should be able to do 40MHz.
	// If the SD card decides to act up again, decrease this to 20MHz and slowly increase again as long as it's stable.
	SD_SCK_MHZ(28),
};

// screen size
constexpr uint16_t SCREEN_WIDTH = 128;
constexpr uint16_t SCREEN_HEIGHT = 64;

// You may have to adjust this for other displays and connections
// This is a SSD1306-based 128 by 64 monochrome OLED which runs on hardware I²C address 0x3C (specified by VCOMH0) without a proper reset pin.
// We could use 128 bytes page buffer if other libraries need a decent amount of memory, change FRAMEBUFFER_SIZE to "1" or "2"
#if FRAMEBUFFER_SIZE == 'F'
using Display = U8G2_SSD1306_128X64_VCOMH0_F_HW_I2C;
#elif FRAMEBUFFER_SIZE == '1'
using Display = U8G2_SSD1306_128X64_VCOMH0_1_HW_I2C;
#elif FRAMEBUFFER_SIZE == '2'
using Display = U8G2_SSD1306_128X64_VCOMH0_2_HW_I2C;
#endif

// Hardware I2C clock speed for the display.
// Even though most displays are run at 400KHz by default, many can be overdriven much higher.
// Increasing this value reduces audio glitches, since the I2C DMA interferes with I2S DMA.
// If the display is broken, reduce this value as much as necessary.
constexpr uint32_t DISPLAY_CLOCK_SPEED = 2'000'000;

//// font stuff
// Main font used for UI text. Any 10-12 px font will allow 4-5 lines of text.
// good fonts:
// u8g2_font_cu12_he (12px height)
// u8g2_font_t0_15_te (10px height)
// u8g2_font_mercutio_basic_nbp_t_all (10px height)
// u8g2_font_unifont_he (12px height)
constexpr auto MAIN_FONT = u8g2_font_mercutio_basic_nbp_t_all;
// Height of the main font in pixels
constexpr uint8_t MAIN_FONT_SIZE = 10;
// Font used for digital clock faces; very large (~1/2 screen height)
constexpr auto CLOCK_FONT = u8g2_font_fur30_tn;
constexpr uint8_t CLOCK_FONT_HEIGHT = 30;
// Tiny font (4-6px height) for debug text and other small elements.
constexpr auto TINY_FONT = u8g2_font_tom_thumb_4x6_t_all;
constexpr uint8_t TINY_FONT_HEIGHT = 5;
// Script font used for various non-UI prose text.
constexpr auto SCRIPT_FONT = u8g2_font_helvR10_te;
// spacing between clock face status symbols
constexpr uint8_t SYMBOL_SPACING = 1;
// Size of the gap between lines. Increase this if lines cut into each other (especially chars like "g")
constexpr uint8_t LINESEP = 3;
// Height of a single line, depends on font size and line separator gap.
constexpr uint8_t LINE_HEIGHT = (MAIN_FONT_SIZE + LINESEP - 1);
// Computed number of lines, depends on screen and line height.
constexpr uint8_t LINE_COUNT = static_cast<uint8_t>(SCREEN_HEIGHT / LINE_HEIGHT);
// How many pixels to shift all text to the right. This makes inverted text look cleaner if greater than 0.
constexpr uint8_t LEFT_TEXT_MARGIN = 1;
// random numbers 1-10 for visual stuff
constexpr double VRAND0 = 2.8876;
constexpr double VRAND1 = 6.209;
constexpr double VRAND2 = 7.1195;
constexpr double VRAND3 = 4.973;

// menuing buttons
constexpr uint8_t PIN_BUTTON_UPDOWN = 0; // prev/next on one analog pin, voltage divider hack (see button reading logic)
constexpr uint8_t PIN_BUTTON_RIGHT = D0; // enter
constexpr uint8_t PIN_BUTTON_LEFT = D3; // back

// button bits, button constants depend on them
constexpr uint8_t BUTTON_UP_BIT = 0;
constexpr uint8_t BUTTON_DOWN_BIT = 1;
constexpr uint8_t BUTTON_RIGHT_BIT = 2;
constexpr uint8_t BUTTON_LEFT_BIT = 3;

// button constants for button press handling
constexpr uint8_t BUTTON_UP = 0b1 << BUTTON_UP_BIT;
constexpr uint8_t BUTTON_DOWN = 0b1 << BUTTON_DOWN_BIT;
constexpr uint8_t BUTTON_RIGHT = 0b1 << BUTTON_RIGHT_BIT;
constexpr uint8_t BUTTON_LEFT = 0b1 << BUTTON_LEFT_BIT;
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

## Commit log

2024-03-12 refined audio handling via timer interrupts
2024-03-12 fix crash when selecting the current directory in the file view menu
2024-03-18 updated board info
2024-03-18 start of a case
2024-03-20 Compression experiment statistics
    [stats.csv]
2024-03-21 fix wrong compression calculation in regards to frame cropping
2024-03-21 fix algorithm name
    LEB is never used here
    [stats.csv]
2024-03-29 case completed
    [MusikWeckerCase_bottom.3mf, MusikWeckerCase_top.3mf]
2024-03-29 OTA, video compression fiddling, debugging via TCP
    [stats.csv]
2024-03-30 try to make audio work again
    - move as much stuff as possible to secondary heap to free up the few K we're missing
    - get sd card back to 30MHz (8 just doesn't work)
    - what the fuck is happening
    [ClockFaces.h, Definitions.h, MusikWecker.ino]
2024-03-30 various documentation updates
    including a reordered todo list
    [stats.csv]
2024-04-12 update schematic to reflect amplifier and speakers
2024-05-05 reduce clock speed when audio is not playing to save power
2024-05-22 usb pd in the schematics
2024-06-09 intra-frame delta calculation
2024-06-11 More menu restructuring & add a retro clock
    Also cut rendering times by using LUT-based trig
2024-07-19 case changes
2024-07-21 final fixes
    [MusikWeckerCase.FCStd]
2025-07-22 make turtle object encoder even better
2025-07-23 use better Rice-Golomb order + AABB optimization in polygon fill
    [deltas.csv, distances.csv]
